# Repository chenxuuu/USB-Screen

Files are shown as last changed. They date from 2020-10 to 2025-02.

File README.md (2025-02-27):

# USB-Screen




低成本PC资源监控小屏幕。如果感兴趣，点个星星呗。

PC monitor screen, only cost $5.

> only Chinese readme now.



## 硬件

- 主控：CH551
- 屏幕：1.4寸IPS彩屏
- 接口：microUSB、typec、排针
- 外壳：3d打印

## 使用的开发软件/框架

- 硬件设计：KICAD
- 嵌入式软件：标准C51 (Keil/SDCC)
- 外壳：OpenSCAD
- PC客户端：WPF (.net framework 4.0)
  - 可根据通讯协议自行开发客户端

## 通讯协议

目前通过`USB CDC`进行通讯。

设备插入后，会被识别为串口设备，设备实例路径为`USB\VID_1A86&PID_5722\ST1E6DIPSF0F0SPI3`

数据包分为两种：

### 包长度小于64字节

这种类型的数据包，将作为`刷新区域设置`+`像素信息`使用，刷新区域的范围为**0~239**，格式如下：

```txt
     1byte         1byte        1byte        1byte         1byte
+-------------+-------------+-----------+--------------+------------+
| data length | width start | width end | height start | height end |
+-------------+-------------+-----------+--------------+------------+
       ↓
|<--length-------------------------------......-->|
        1byte                1byte
+-------------------+------------------+------
| rgb565 high 8 bit | rgb565 low 8 bit |......
+-------------------+------------------+------
```

像素数据顺序为从左至右从上至下刷新，每个像素点的颜色为2字节，遵循`rgb565`色彩格式，如下

```txt
    1byte       1byte
+-----------+-----------+
| rrrr rggg | gggb bbbb |
+-----------+-----------+
```

#### `data length`的使用特例

因为`data length`包最长也只能为`59`，所以进行了额外定义：

1. `data length`的值为`0xC0`为亮度调节命令，后接1byte亮度参数，用于调节屏幕背光亮度
```txt
    1byte       1byte
+-----------+------------+
| 1100 0000 | brightness |
+-----------+------------+
```

2. `data length`的最高位`0x80`如果为1，则表示当前模式为黑白模式，此模式下1字节代表8个像素点，设备会将所有数据按黑白模式进行处理

3. `data length`的倒数第二高位`0x40`如果为1，则表示后面的数据全部为像素数据，同时`data length`剩下字节表示后面跟随数据的长度，注意总包长度必须小于64字节

```txt
     1byte
+---------------+
| 0x40 & length |
+---------------+
           ↓
|<-------length-----------------------......-->|
        1byte                1byte
+-------------------+------------------+------
| rgb565 high 8 bit | rgb565 low 8 bit |......
+-------------------+------------------+------
```

### 包长度等于64字节

64字节数据将全部作为像素数据发送至屏幕

```txt
        1byte               1byte              1byte               1byte
+-------------------+------------------+-------------------+------------------+---
| rgb565 high 8 bit | rgb565 low 8 bit | rgb565 high 8 bit | rgb565 low 8 bit |...
+-------------------+------------------+-------------------+------------------+---
```

## 功能

PC控制端正在制作中

欢迎[提建议](https://github.com/chenxuuu/USB-Screen/issues)或直接参与开发。

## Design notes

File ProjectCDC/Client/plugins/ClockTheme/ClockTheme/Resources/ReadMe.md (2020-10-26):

Version_1.0

StackingOrder(堆叠顺序) must use png:
Background.png
Backdrop.png
Dial.png
Pointer_Hour.png
Pointer_Minute.png
Pointer_Second.png

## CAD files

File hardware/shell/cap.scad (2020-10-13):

//长宽高
ma=32.3;//横着
mb=34.3;//竖着
mc=4.2;//厚度

l1=1.6;//屏幕顶部
l2=2;//两边
l3=4.8;//屏幕底部

ll=3;//默认槽宽


difference()
{
    union()
    {
        translate([0,-2,mb/2+1])
            cube([ma-0.4,mc+4-0.2,2.8],true);
        difference()//两边的脚
        {
            translate([0,-5,mb/2-7])
                cube([ma+2,2,15],true);
            translate([0,-5,mb/2-7])
                cube([ma-3,2.1,18],true);
        }
    }
    union()
    {
        include<usb_screen.scad>;
        translate([6,-2.5,5])
            cube([12,5,mb],true);//usb口
    }
}

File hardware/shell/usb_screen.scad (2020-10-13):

//长宽高
ma=32.3;//横着
mb=34.3;//竖着
mc=4.2;//厚度

l1=1.6;//屏幕顶部
l2=2;//两边
l3=4.8;//屏幕底部

ll=3;//默认槽宽


difference()
{
    cube([ma+4,mc+4,mb+5],true);
    union()
    {
        cube([ma,mc,mb],true);//中间的空间
        translate([0,0,-1.5])//屏幕排线
            cube([ma-10,mc,mb],true);
        
        translate([0,3,0])//前面扣洞
            cube([ma-l2*2,mc,mb-l3*2],true);
        translate([0,3,mb/4+0.5])//前面再扣洞
            cube([ma-l2*2,mc,mb/2-l2*2],true);
        translate([0,-3,0])//背面扣洞
            cube([ma-ll,mc,mb-ll],true);
        
        translate([0,0,5])//上面扣洞
            cube([ma,mc,mb],true);
        translate([0,-3,10])//去掉一个梁
            cube([ma-ll,mc,mb-ll],true);

        translate([0,-3,mb/2+1])//做个槽放盖子
            cube([ma,mc,3.5],true);
    }
}
translate([0,-7.5,0])//背面
    cube([ma+4,2,mb+5],true);

difference()
{
    translate([0,-5,0])//背面
        cube([ma+4,3,mb+5],true);
    translate([0,-5,0])//背面
    union()
    {
        translate([0,0,5])//上面扣洞
            cube([ma,mc,mb+10],true);
        translate([0,0,3])//卡扣
            cube([ma+5,4,4],true);
    }
}

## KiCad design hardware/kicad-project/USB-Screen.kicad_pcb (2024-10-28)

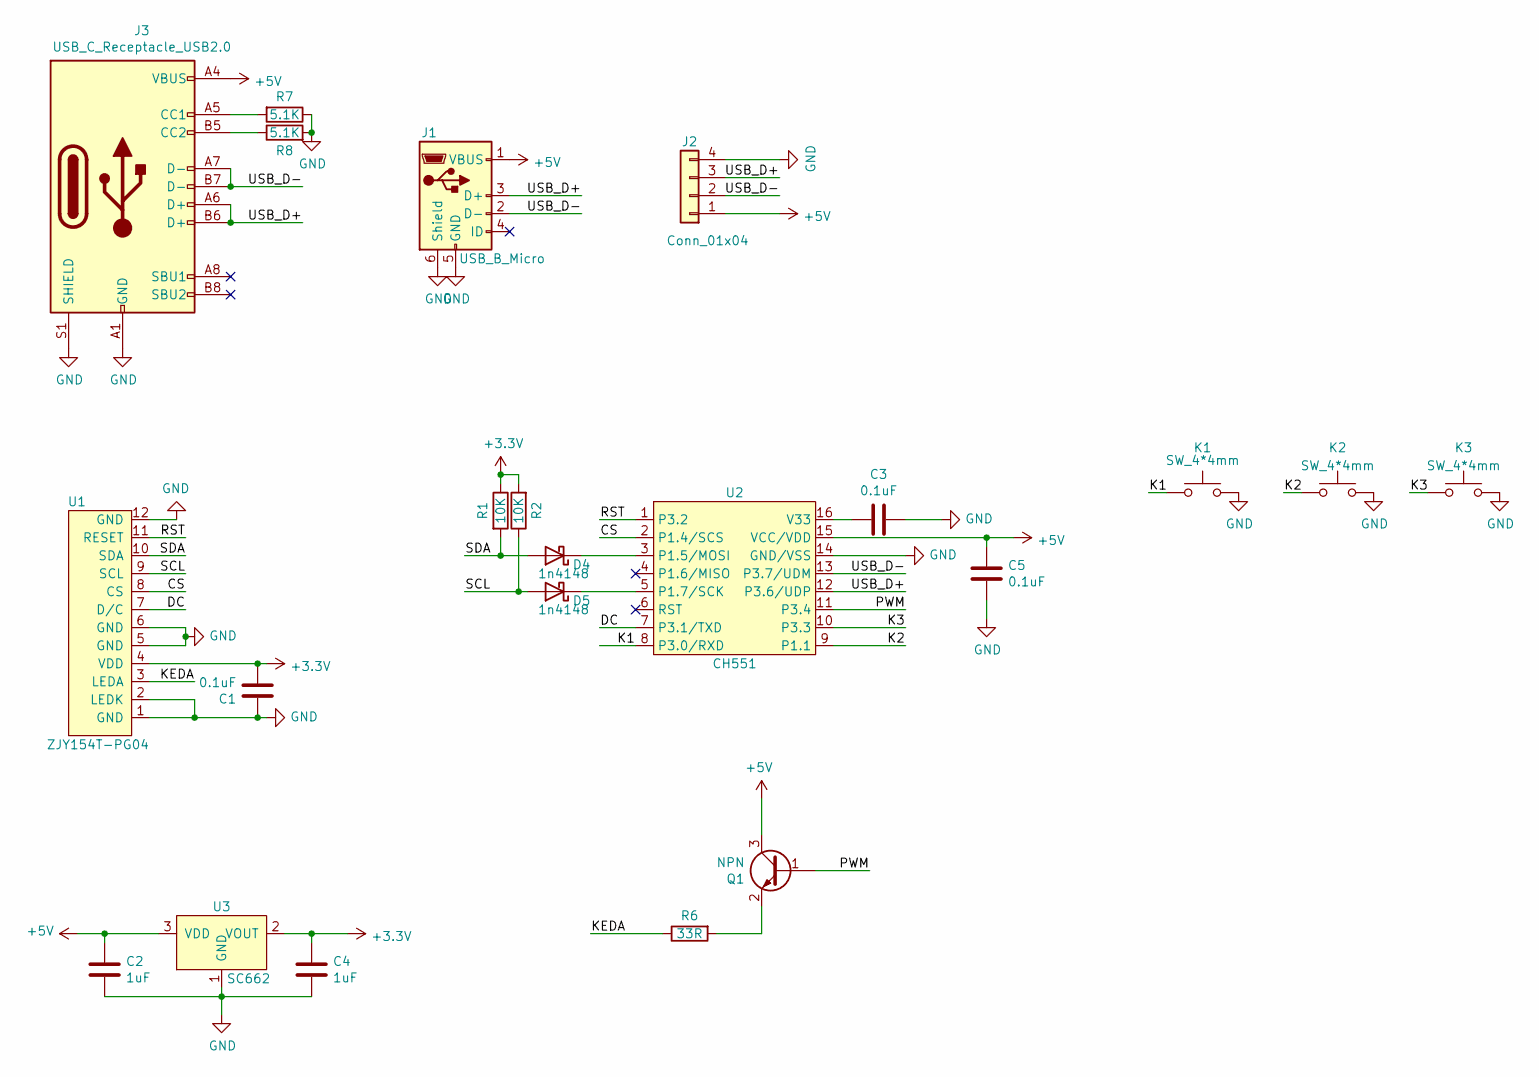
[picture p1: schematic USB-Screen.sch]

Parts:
C1, C3, C5: 0.1uF; C_0402_1005Metric
C2, C4: 1uF; C_0402_1005Metric
D4, D5: 1n4148; D_SOD-323
J1: USB_B_Micro; USB_Micro-B_Molex-105017-0001
J2: Conn_01x04; PinHeader_1x04_P2.54mm_Vertical_SMD_Pin1Left
J3: USB_C_Receptacle_USB2.0; USB_C_Receptacle_Steady_UTC16-G
K1, K2, K3: SW_4*4mm; SW_Push_1P1T_NO_4x4mm_H2.0mm
Q1: NPN; SOT-23
R1, R2: 10K; R_0402_1005Metric
R6: 33R; R_0402_1005Metric
R7, R8: 5.1K; R_0402_1005Metric
U1: ZJY154T-PG04
U2: CH551; SOP-16_4.55x10.3mm_P1.27mm
U3: SC662; SOT-23

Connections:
+3V3: C1.2, C4.1, R1.1, R2.2, U1.4 (VDD), U3.2 (VOUT)
+5V: C2.1, C5.1, J1.1 (VBUS), J2.1, J3.A4 (VBUS), J3.A9 (VBUS), J3.B4 (VBUS), J3.B9 (VBUS), Q1.3 (C), U2.15 (VCC/VDD), U3.3 (VDD)
/CS: U1.8 (CS), U2.2 (P1.4/SCS)
/DC: U1.7 (D/C), U2.7 (P3.1/TXD)
/K1: K1.1, U2.8 (P3.0/RXD)
/K2: K2.1, U2.9 (P1.1)
/K3: K3.1, U2.10 (P3.3)
/KEDA: R6.1, U1.3 (LEDA)
/PWM: Q1.1 (B), U2.11 (P3.4)
/RST: U1.11 (RESET), U2.1 (P3.2)
/SCL: D5.2 (A), R2.1, U1.9 (SCL)
/SDA: D4.2 (A), R1.2, U1.10 (SDA)
/USB_D+: J1.3 (D+), J2.3, J3.A6 (D+), J3.B6 (D+), U2.12 (P3.6/UDP)
/USB_D-: J1.2 (D-), J2.2, J3.A7 (D-), J3.B7 (D-), U2.13 (P3.7/UDM)
GND: C1.1, C2.2, C3.1, C4.2, C5.2, J1.5 (GND), J1.6 (Shield), J2.4, J3.A1 (GND), J3.A12 (GND), J3.B1 (GND), J3.B12 (GND), J3.S1 (SHIELD), K1.2, K2.2, K3.2, R7.1, R8.2, U1.1 (GND), U1.2 (LEDK), U1.5 (GND), U1.6 (GND), U1.12 (GND), U2.14 (GND/VSS), U3.1 (GND)
unnamed: C3.2, U2.16 (V33)
unnamed: D4.1 (K), U2.3 (P1.5/MOSI)
unnamed: D5.1 (K), U2.5 (P1.7/SCK)
unnamed: J3.A5 (CC1), R7.2
unnamed: J3.B5 (CC2), R8.1
unnamed: Q1.2 (E), R6.2

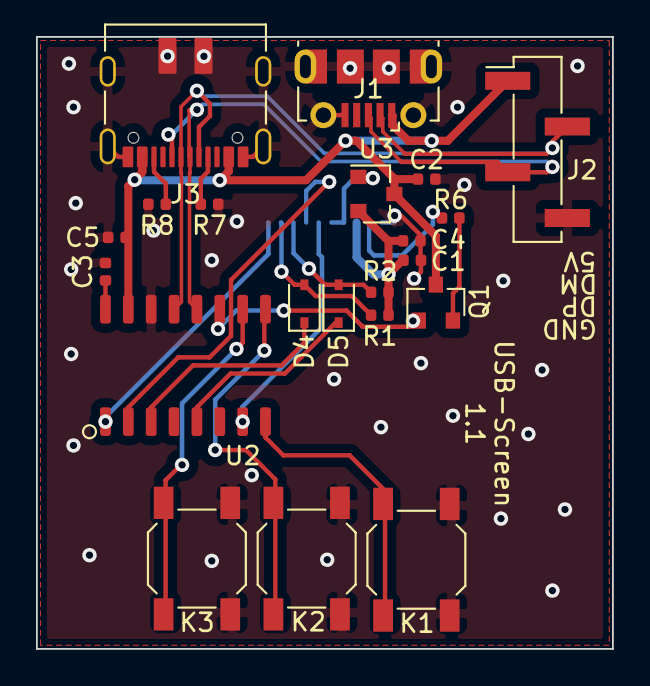
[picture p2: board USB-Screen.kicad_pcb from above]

Board: 2 copper layers, 32.0 x 34.0 mm, 22 parts (1 on the bottom side), 21 nets.

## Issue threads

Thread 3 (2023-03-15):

发送图片到屏幕上

istrashguy, 2023-03-15:
怎么将一张图片发送到已经连接好的IPS屏幕上，硬件均为教程一致，没看明白源码提供了什么

chenxuuu, 2023-03-15:
参考[通信协议](https://github.com/chenxuuu/USB-Screen#%E9%80%9A%E8%AE%AF%E5%8D%8F%E8%AE%AE)与[上位机代码](https://github.com/chenxuuu/USB-Screen/blob/master/ProjectCDC/Client/UsbScreen/Models/SerialScreen.cs#L207)

istrashguy, 2023-03-16:
抱歉，我对c#语言并不熟悉，但看出了projectcdc目录下的Client文件夹或许是关键，用VS打开UsbScreen.sln文件后我认为MainWindow.xaml.cs，我运行时出现了Newtonsoft.Json包导入失败的问题，请问我以上分析与问题该如何解决，如果我想的不对，还请指出，谢谢!

chenxuuu, 2023-03-16:
还原一下nuget重新打开工程即可

不会c#的话照着协议手写就行

---原始邮件---
发件人: ***@***.***&gt;
发送时间: 2023年3月16日(周四) 晚上7:34
收件人: ***@***.***&gt;;
抄送: ***@***.***&gt;;"State ***@***.***&gt;;
主题: Re: [chenxuuu/USB-Screen] 发送图片到屏幕上 (Issue #3)

抱歉，我对c#语言并不熟悉，但看出了projectcdc目录下的Client文件夹或许是关键，用VS打开UsbScreen.sln文件后我认为MainWindow.xaml.cs，我运行时出现了Newtonsoft.Json包导入失败的问题，请问我以上分析与问题该如何解决，如果我想的不对，还请指出，谢谢!

—
Reply to this email directly, view it on GitHub, or unsubscribe.
You are receiving this because you modified the open/close state.Message ID: ***@***.***&gt;

istrashguy, 2023-03-18:
抱歉再次打扰到你，我按照通信协议的格式设置了数据包，将长宽开始与结束都设置为了239，0 ;但是运行后屏幕无反应，以下为python代码：

# RGB565中 高低位对应二进制
import serial
data_high = 0b00000000  # 0x00
data_low = 0b00011111    # 0x1F
data_length = len(hex(data_high)) + len(hex(data_low))
print(data_length)
width_start = 0
width_end = 239
height_start = 0
height_end = 239

data = bytearray([
    data_length, width_start, width_end, height_start, height_end, data_high, data_low
])
screen = serial.Serial('COM3', 115200, timeout=1)
screen.write(data)

如果哪有错请指出或者给我一份示例代码参考，谢谢

Closed 2023-03-16.

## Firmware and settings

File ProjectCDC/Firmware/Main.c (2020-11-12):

#include <string.h>
#include "CH552.h"
#include "Freqsys.h"

#include "LCD.h"
#include "UsbManager.h"

sbit	K1	= P3^0;
sbit	K2	= P1^1;
sbit	K3	= P3^3;

/*******************************************************************************
* Function Name	: IOport_Init
* Description	: IO口默认状态配置位
* Input			: None
* Return		: None
*******************************************************************************/
void IOport_Init(void)
{
	LCD_BLK = 0;
	while(USB_DEV_AD==0);
	LCD_BLK = 1;
	P3 = 0xFF;
	P1 = 0xFF;
}

/*******************************************************************************
* Function Name	: PWM_Init
* Description	: PWM初始化(PWM2输出引脚为P3.4)
* Input			: None
* Return		: None
*******************************************************************************/
void PWM_Init()
{
	PWM_CK_SE	= 0x01;			// PWM时钟分频设置
	PWM_DATA2	= 0x7F;			// PWM2占空比设置(占空比=PWM_DATA2/256)
	PWM_CTRL	= bPWM2_OUT_EN;	// PWM2输出使能
}

/*******************************************************************************
* Function Name	: main
* Description	: 主函数
* Input			: None
* Return		: None
*******************************************************************************/
void main(void)
{
	setFsys();					// 初始化系统时钟
	PWM_Init();					// 初始化PWM功能
	USB_DeviceInit();			// 初始化USB功能
	EA  = 1;					// 使能单片机全局中断
	IOport_Init();				// 初始化IO口状态
	LCD_Init();					// 初始化LCD屏幕
	while(1)
	{
		if(DMA_STATUS & 0x01)
		{
			ROM_DATA_H = DMA_STATUS&0x10;
			LCD_SET(Ep3Buffer);
			DMA_STATUS &= (~0x11);
			if((UDEV_CTRL&bUD_GP_BIT) == 0) 
			{
				UEP3_CTRL = UEP3_CTRL & ~MASK_UEP_R_RES | UEP_R_RES_ACK;
			}
		}
		else if(DMA_STATUS & 0x02)
		{
			ROM_DATA_H = DMA_STATUS&0x20;
			LCD_SET(Ep4Buffer);
			DMA_STATUS &= (~0x22);
			if((UDEV_CTRL&bUD_GP_BIT) != 0) 
			{
				UEP3_CTRL = UEP3_CTRL & ~MASK_UEP_R_RES | UEP_R_RES_ACK;
			}
		}
	}
}

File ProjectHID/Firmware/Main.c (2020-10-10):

#include <stdio.h>
#include <string.h>
#include "CH552.h"
#include "TypeDefines.h"
#include "UsbReports.h"
#include "SPI.h"
#include "UsbManager.h"

sbit	Bg_Led1	= P3^0;
sbit	Bg_Led2 = P3^3;
sbit	Bg_Led3 = P1^1;

/*******************************************************************************
* Function Name	: SetFsys
* Description	: 设置系统时钟频率
* Info			: 内核时钟12MHz
				: PLL倍频=96MHz
				: USB时钟分频器=96MHz/48MHz		(USB模块工作需要48MHz频率)
				: 系统时钟分频器=96MHz/24MHz
*******************************************************************************/
void SetFsys()
{
	SAFE_MOD	= 0x55;		//解锁安全模式
	SAFE_MOD	= 0xAA;
	CLOCK_CFG	= 0x86;		//系统时钟分频器4分频=24MHz
}
/*******************************************************************************
* Function Name	: IOport_Init
* Description	: IO口默认状态配置位
* Input			: None
* Return		: None
*******************************************************************************/
void IOport_Init(void)
{
	LCD_BLK = 0;
	while(USB_DEV_AD==0);
	LCD_BLK = 1;
	P3 = 0xFF;
	P1 = 0xFF;
    P1_DIR_PU  = 0x1F;		// 第7,6,5位禁用上拉(注意需要外接3.3V弱上拉10K电阻)
}

/*******************************************************************************
* Function Name	: main
* Description	: 主函数
* Input			: None
* Return		: None
*******************************************************************************/
void main(void)
{
	SetFsys();					// 初始化系统时钟
	USB_DeviceInit();			// 初始化USB功能
	EA  = True;					// 使能单片机全局中断
	IOport_Init();				// 初始化IO口状态
	LCD_Init();
	while(true)
	{
		LCD_BLK = IsUsbShut;	// 电脑关机后熄灭屏幕背光
	}
}

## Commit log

2020-09-15 完成原理图
    [USB-Screen.kicad_pcb, USB-Screen.sch]
2020-09-15 pcb完成
    [USB-Screen.kicad_pcb, USB-Screen.sch]
2020-09-15 微调，打样
    [USB-Screen.kicad_pcb, USB-Screen.sch]
2020-09-18 补上两个头文件
2020-09-18 上传pdf手册
2020-09-22 先把示例代码搬过来
2020-09-22 spi代码也抄过来，待改
2020-09-23 上传3d外壳模型大体形状，待改
    [usb_screen.scad]
2020-09-27 我也不知道为啥屏幕不亮，先把代码传上来
2020-09-28 屏幕能量了，但是亮度好低
2020-09-28 hid发spi数据
2020-09-28 简单描述协议
2020-09-28 更正背光电路
    [USB-Screen.kicad_pcb, USB-Screen.sch]
2020-09-29 稍微改改初始化参数，优化下屏幕效果
2020-09-29 新建一个pc端项目
2020-09-29 简单测试hid收发
2020-09-29 不知道为啥显示效果不对，明天再调
2020-09-30 用软件spi才能用这屏
2020-09-30 可以显示图片了
2020-09-30 加个进度条
2020-09-30 干掉窗口边框
2020-09-30 事件绑定与UI分离
2020-09-30 优化逻辑，提升刷屏速度到10秒左右
2020-10-01 修改 .gitignore规则
2020-10-05 修改过滤规则,并添加bootloader和新的Firmvare工程
2020-10-05 上位机勉强能用了
2020-10-05 上位机可选使用硬件SPI还是软件SPI,上位机添加固件更新功能.
2020-10-05 屏蔽输出反馈的数据
2020-10-05 下位机启用4路端口接收数据
2020-10-05 调整下位机SPI代码
2020-10-05 硬件SPI初始化屏幕成功
2020-10-06 使用4通道HID传输数据,速度大有改善!
2020-10-06 整理工程结构,将HID驱动的显示屏工程单独存放
2020-10-06 修复数据卡死后无法更新固件的BUG
2020-10-06 添加数据传输耗时统计
2020-10-06 过滤无关的HID设备插拔事件,防止干扰.
2020-10-07 使下位机反馈完整数据(开销忽略不计)
2020-10-07 使用线程安全的队列,以解决偶尔出现的取值null问题.
2020-10-07 使用异步多线程发送数据,提升效率(虽然看不出什么卵用)
2020-10-08 更正编译报错
2020-10-09 检查数据包同步标志
2020-10-09 USBCDC模式传输数据,大幅提升速度. 刷屏一页耗时0.4s
2020-10-10 调整硬件SPI上拉电压,解决硬SPI刷屏闪烁问题.
2020-10-10 sda、clk加上拉电阻，去掉下载电路焊盘
    [USB-Screen.kicad_pcb, USB-Screen.sch]
2020-10-10 修改CDC配置以使用SPI外部上拉
2020-10-10 提交HID+CDC调试工具
2020-10-10 C# 串口发送不出去数据,找不到原因.
2020-10-10 串口代码能用
2020-10-10 老代码挪个地方
2020-10-10 解决主机获取字符串描述符失败的BUG PS:是由于指针类型不一致导致的(编译器竟然不报错)
2020-10-10 调整测试代码,临时解决数据错位的问题.
2020-10-10 添加测试用数据
2020-10-11 再次提升CDC通信速度,现在刷屏只需要0.3s内.
2020-10-11 初步调通上位机,勉强能用了.
2020-10-11 调整工程目录结构,方便管理
2020-10-11 删除未用的头文件引用
2020-10-11 添加一个简易实现的持续截图推送功能(资源占用巨大)
2020-10-12 更改spi外设逻辑，稍微提高效率
2020-10-12 解决上位机频繁截图会导致资源消耗过大的问题.
2020-10-12 再次提升刷屏效率，现在可以达到0.19s/帧
2020-10-12 修改SPI总线分压电路
    [USB-Screen.sch]
2020-10-12 优化SPI逻辑，提升SPI速度
2020-10-12 给电路图添加多种备用调试方案
    [USB-Screen.sch]
2020-10-12 调整外设初始化顺序
2020-10-12 用二极管实现电平转换
    [USB-Screen.sch]
2020-10-12 重新布线
    [USB-Screen.kicad_pcb, USB-Screen.sch]
2020-10-12 IO初始化逻辑还是改回去吧。。。
2020-10-12 外壳的大概样子
    [usb_screen.scad]
2020-10-12 修改通讯协议,再次提升效率,现在刷新1帧只需要0.165s左右
2020-10-13 加上盖子
    [cap.scad, usb_screen.scad]
2020-10-13 感觉没什么提升空间了,551的SPI速度太拉跨了.
2020-10-13 更改目录结构
    [USB-Screen.kicad_pcb, USB-Screen.sch, cap.scad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]
2020-10-13 盖子改得规则一点
    [cap.scad, usb_screen.scad]
2020-10-13 修改注释
2020-10-13 优化内存使用，减少GC发生率
2020-10-13 下位机添加黑白模式
2020-10-13 对中途拔出串口进行处理,避免程序崩溃.
2020-10-13 二极管换成小封装的
    [USB-Screen.kicad_pcb, USB-Screen.sch]
2020-10-13 拔出usb后不需要关闭串口.
2020-10-13 Create main.yml
    测试Actions自动编译
2020-10-13 微调外壳
    [cap.scad, usb_screen.scad]
2020-10-13 修改上位机的事务逻辑,好像变方便了一点? 虽然代码有点混乱,后面再优化吧.
2020-10-14 加上typec座
    [USB-Screen.sch]
2020-10-14 更改pcb布局
    [USB-Screen.kicad_pcb, USB-Screen.sch]
2020-10-14 三个led改成按键
    [USB-Screen.kicad_pcb, USB-Screen.sch]
2020-10-14 完善readme
2020-10-14 readme 需要严谨一点.
2020-10-14 调整变量声明
2020-10-14 添加一个debug信息打印点
2020-10-15 cpp的东西都删了，让GitHub能正常识别
2020-10-15 编译时移除未使用的函数
2020-10-15 添加俩个3D封装
    [USB-Screen.kicad_pcb, USB-Screen.sch]
2020-10-15 添加自定义3D模型
    [USB-Screen.kicad_pcb]
2020-10-15 3d模型
2020-10-15 更正拼写错误
    [USB-Screen.kicad_pcb, USB-Screen.sch, cap.scad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]
2020-10-15 Update main.yml
    仅修改上位机部分代码后才编译
2020-10-16 加上通讯协议解释
2020-10-16 更正笔误
2020-10-16 笔误x2
2020-10-16 换成微软官方的msbuild环境
2020-10-16 pr也加上
2020-10-16 加上固件的ci
2020-10-16 更正ci
2020-10-16 测试下ci
2020-10-17 修复usb协议栈的bug
2020-10-17 修改默认波特率参数(好像并没有用)
2020-10-17 修改编译优化等级Lv9
2020-10-17 修改端点报告周期和USB协议版本 然而还是没能找到USBCDC连接HUB竟然比直连PC速度更快的原因.
2020-10-17 修改Bootloader控制命令
2020-10-18 完成CDCBootloader
2020-10-18 更正函数名称
2020-10-18 CDCBootloader 设备描述符
2020-10-18 BootloaderCDC初步测试能用了 可能丢包,需要添加反馈命令超时判断.
2020-10-19 行增数据长度1-62的发包模式(不携带命令),使用D6位作为识别.
2020-10-19 修复一个指令位定义搞反了的bug
2020-10-19 修复取数据指针问题.
2020-10-20 测试刷屏库
2020-10-20 修复黑白模式的取指针BUG
2020-10-20 修复黑白模式,移位寄存器未赋值的bug
2020-10-20 双色图像显示功能
2020-10-20 更新协议解释
2020-10-20 屏幕类的数据绑定处理
2020-10-20 稍微改改
2020-10-20 文件夹名字改一下
2020-10-20 简单摆了点东西
2020-10-21 串口断开自动重连逻辑
2020-10-21 界面摆一摆
2020-10-21 dll插件加载与例子
2020-10-21 启动自动连接上次串口，预览图实时更新
2020-10-21 调整usb协议栈
2020-10-21 插件已经能跑，预览图不正常
2020-10-22 简化字符串格式化
2020-10-22 使屏幕内容可以正常预览
2020-10-23 标题栏跟随系统颜色
2020-10-23 调整列表获取逻辑
2020-10-23 调整图片颜色数据的处理方式
2020-10-23 设备断开后停止刷新数据
2020-10-23 修改窗口样式
2020-10-23 实现例子插件功能
2020-10-23 修正图片长宽写反了的BUG
2020-10-23 试试彩虹渐变,看起来不错.
2020-10-23 添加指针时钟插件
2020-10-24 稍微美化时钟
2020-10-24 解决插件重复调用导致的Bitmap多线程冲突问题。
2020-10-24 修改变量为属性
2020-10-24 给时钟添加文字信息
2020-10-24 优化图像处理性能
2020-10-24 解除对Dll的锁定,载入dll后可以删除文件.
2020-10-25 时针半透明处理,这样可以透出下方的文字.
2020-10-25 PCB直插方案
    [USB-Screen2.kicad_pcb]
2020-10-25 规范插件命名规则 #主类#副类#次类#编号#
2020-10-26 修改插件风格
2020-10-26 修改文件名称
2020-10-26 添加新的时钟插件(可使用外部PNG主题资源)
2020-10-26 调整客户端UI参数
2020-10-26 新插件功能,调用外部图片绘制时钟
2020-10-30 删除未用的函数参数
2020-11-11 添加亮度调节命令
2020-11-11 增加亮度控制功能
2020-11-11 修复亮度调节命令穿插在数据命令之中会导致花屏的BUG
2020-11-11 使用0xC0作为亮度调节命令
2020-11-12 优化代码结构,压缩hex体积.
2020-11-12 改0402封装为0603封装,对手工焊接更友好.
    [USB-Screen2.kicad_pcb]
2020-11-12 设置Gerber生成配置
    [USB-Screen2.kicad_pcb]
2023-03-19 Update README.md
    增加亮度指令说明
2024-10-28 update: 我也不知道改了啥
    [USB-Screen.kicad_pcb]
2025-01-02 add: 几个新文件
